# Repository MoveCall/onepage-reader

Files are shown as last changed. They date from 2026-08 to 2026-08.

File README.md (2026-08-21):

<div align="center">

<a href="https://github.com/MoveCall/onepage-reader">
  <picture>
    <source media="(prefers-color-scheme: dark)" srcset="assets/logo-dark.svg">
    OnePage Logo
  </picture>
</a>

# OnePage Reader

**Open-Hardware DIY E-Reader Ecosystem**  
*Firmware · Custom Board · Enclosure · Browser Tools*

<br/>







<br/>

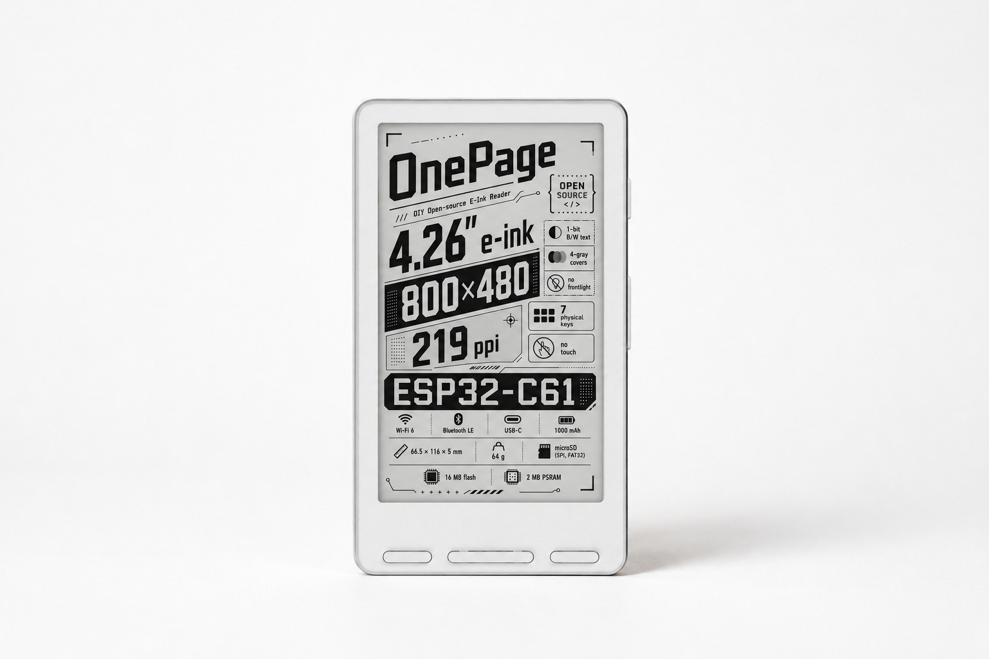
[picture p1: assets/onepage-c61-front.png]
OnePage C61 Front View


<br/>
<br/>

</div>

---

##  Overview

**OnePage** is an open-hardware DIY e-reader built around the **ESP32-C61** RISC-V wireless SoC. 

This repository serves as the central hub of the entire ecosystem: it houses the complete electronic fabrication packages (schematic, PCB, BOM, iBOM) and mechanical panel files, while aggregating the firmware, board SDK, and web companion tools via Git submodules.

---

##  Key Features

- **Next-Gen ESP32-C61**: Low-power RISC-V core with integrated Wi-Fi 6 and BLE.
- **BLE Page-Turner Remote**: Supports Bluetooth remote page turning with battery monitoring, key swapping, and live scanning.
- **Web Companion Tools**:
  - **Web Serial Flasher**: Flash firmware directly from Chromium-based browsers without local toolchain setups.
  - **Online Font Tool (`cpfont`)**: In-browser CJK font subsetting and glyph rasterization.
- **Production-Ready Hardware**: Complete gerbers, pick-and-place files, schematic PDF, and interactive BOM (iBOM).
- **Hybrid Craftsmanship**: Clean PET front and acrylic rear panels with an optional CNC mid-frame and MakerWorld 3D printable shell.

---

##  Ecosystem & Repositories

| Component | Submodule / Link | Description |
|:---|:---|:---|
|  **Firmware** | [`firmware/`](firmware) → [crosspoint-onepage](https://github.com/MoveCall/crosspoint-onepage) | Port of [CrossPoint Reader](https://github.com/crosspoint-reader/crosspoint-reader) tailored for OnePage C61 (`v0.1.0`). |
|  **Board SDK** | *(Nested in firmware)* → [onepage-reader-sdk-arduino](https://github.com/MoveCall/onepage-reader-sdk-arduino) | Arduino & PlatformIO board-support drivers (EPD, keys, power management, SD). |
|  **Electronics** | [`electronics/c61/`](electronics/c61/) | Schematic, Gerbers, BOM, iBOM, and SMT pick-and-place data. |
|  **Enclosure & Panels** | [`mechanical/c61/`](mechanical/c61/) → [MakerWorld](https://makerworld.com.cn/zh/@MoveCall) | Custom PET / Acrylic panels (`.epanm`), CNC mid-frame, and MakerWorld 3D models. |
|  **Web Tools** | [`web/`](web) → [onepage-reader-web](https://github.com/MoveCall/onepage-reader-web) | Official website, WebSerial flasher, and `cpfont` builder. |

---

##  Quick Start

### 1. Clone with all Submodules

To clone the entire project including firmware, drivers, and web tools in one shot:

```bash
git clone --recursive git@github.com:MoveCall/onepage-reader.git
```

If you already cloned without `--recursive`:
```bash
git submodule update --init --recursive
```

### 2. Flash Firmware via Browser

No need to install Python or compilation toolchains — visit the Web Flasher from Chrome / Edge to flash the latest release via USB-C:
[Open Web Flasher](https://github.com/MoveCall/onepage-reader-web)

---

##  Repository Layout

```text
onepage-reader/
├── firmware/        Submodule → crosspoint-onepage (nested: onepage-reader-sdk-arduino)
├── web/             Submodule → onepage-reader-web (browser flasher & font tools)
├── electronics/     PCB design, schematics & fabrication files per hardware variant
│   └── c61/
├── mechanical/      Panels (.epanm), CNC models (.stl) & MakerWorld 3D model links
│   └── c61/
└── assets/          Logos, graphics & media assets
```

---

##  Licensing

This is a **mixed-license** project designed to balance open hardware collaboration with design protection:

- **Electronics & Docs** (this repository): **[CC-BY-SA-4.0](https://creativecommons.org/licenses/by-sa/4.0/)** (`/electronics` may additionally carry **CERN-OHL-S** for hardware designs).
- **Firmware & SDK**: **[MIT](firmware/LICENSE)** (preserves CrossPoint Reader copyright).
- **3D Enclosure**: **[MakerWorld Exclusive License](https://makerworld.com.cn/zh/@MoveCall)** — 3D printable models are distributed exclusively via MakerWorld and are **not** stored directly in this repository.
- **OnePage Name & Logo**: All Rights Reserved.

---

##  Acknowledgements

- Built on top of the [CrossPoint Reader](https://github.com/crosspoint-reader/crosspoint-reader) project (MIT © Dave Allie). *(Not affiliated with CrossPoint or Xteink)*.
- Powered by Espressif ESP32-C61 & Open-Source Community.

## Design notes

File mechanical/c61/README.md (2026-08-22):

# OnePage enclosure & panels — ESP32-C61 (variant: c61)

## 3D Printable Enclosure (MakerWorld)

> **The full 3D printable enclosure models are published on MakerWorld under the MakerWorld Exclusive License.**  
> - Designer profile: **https://makerworld.com.cn/zh/@MoveCall**  
> - OnePage C61 enclosure model: **<model link — TBD after upload>**  

## Files in this Directory

### Front/Back Panels
- [`OnePage_Front_PET_Panel_v1.0.epanm`](OnePage_Front_PET_Panel_v1.0.epanm) — Front PET panel project (LCEDA / 立创面板定制工程)
- [`OnePage_Back_Acrylic_Panel_v1.0.epanm`](OnePage_Back_Acrylic_Panel_v1.0.epanm) — Back Acrylic panel project (LCEDA / 立创面板定制工程)
- [`OnePage_Panel_v1.0.dxf`](OnePage_Panel_v1.0.dxf) — 2D CAD panel fabrication drawing (laser cutting / CNC machining / CAD tools)

### Structural Parts
- [`OnePage_MidFrame_CNC_v1.0.step`](OnePage_MidFrame_CNC_v1.0.step) — CNC mid-frame 3D CAD model (STEP format for machining / CAM)
- [`OnePage_MidFrame_CNC_v1.0.stl`](OnePage_MidFrame_CNC_v1.0.stl) — CNC mid-frame 3D mesh model (STL format)

### Documentation & Guides (Planned)
- `assembly.md` *(optional)* — Assembly guide, screws & heat-set insert specs.
- `print-settings.md` *(optional)* — Recommended print settings and material guidelines.

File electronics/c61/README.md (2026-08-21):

# OnePage electronics — ESP32-C61 (variant: c61)

PCB design for the OnePage C61 board. Designed in **LCEDA / EasyEDA (立创EDA)**.

## Source of truth

- LCEDA source project — either the exported project file (`*.epro` / JSON) committed under
  `lceda/`, **or** the LCEDA open-hardware page on oshwhub: **<oshwhub link — TBD>**.
  (If the design lives on oshwhub, link it here and keep the exported/fab files below in-repo.)

## Hardware Release Files (V1 - 2026-08-19)

Tool-agnostic fabrication and review files for direct manufacturing or reference:

- **Schematic**: [`SCH_Sch_OnePage_V1_2026-08-19.pdf`](SCH_Sch_OnePage_V1_2026-08-19.pdf) — Complete circuit schematic.
- **Gerber / Fabrication**: [`Gerber_PCB_OnePage_V1_2026-08-19.zip`](Gerber_PCB_OnePage_V1_2026-08-19.zip) — PCB gerber & drill files for PCB manufacturing (JLCPCB / any PCB fab).
- **Bill of Materials (BOM)**: [`BOM_Board1_PCB_OnePage_V1_2026-08-19.csv`](BOM_Board1_PCB_OnePage_V1_2026-08-19.csv) — SMT component list.
- **Interactive BOM (iBOM)**: [`InteractiveBOM_PCB_OnePage_V1_2026-8-19.html`](InteractiveBOM_PCB_OnePage_V1_2026-8-19.html) — Visual component placement helper for manual assembly / inspection.
- **Pick and Place (CPL)**: [`PickAndPlace_PCB_OnePage_V1_2026_08_19.csv`](PickAndPlace_PCB_OnePage_V1_2026_08_19.csv) — SMT placement coordinates.
- **PCBA Preview**: [`pcb'a-pic.webp`](pcb'a-pic.webp) — Board rendering / photo.

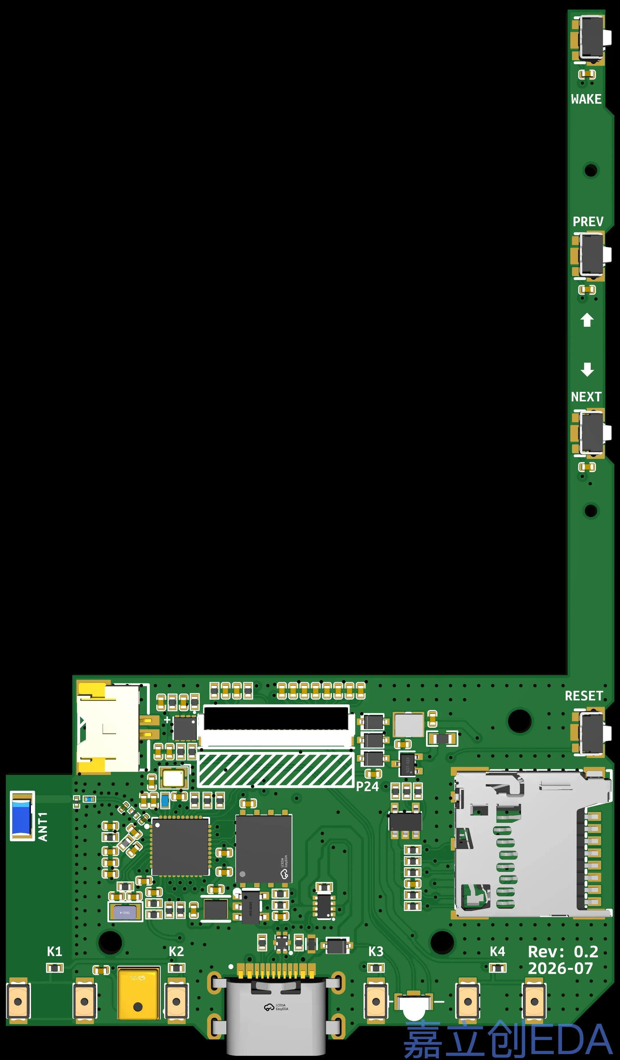
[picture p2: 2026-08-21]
electronics/c61/pcb'a-pic.webp

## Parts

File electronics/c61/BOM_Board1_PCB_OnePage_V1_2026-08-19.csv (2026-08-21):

Comment | Designator | Footprint | Quantity | Supplier Part
RFANT3216120A5T | ANT1 | FILTER-SMD_1206-2P-L3.2-W1.6-L | 1 | C127629
100nF | C1,C2,C11,C14,C16,C19,C21,C22,C26,C28,C34,C35,C36,C37 | C0402 | 14 | C41851,C307331
1uF | C3,C4,C6,C7,C8,C9,C10,C12,C13,C15,C17,C18,C23,C29,C38 | C0402 | 15 | C52923
4.7uF | C5 | C0402 | 1 | C2858031
10uF | C20,C24,C25,C27,C32,C39,C44 | C0402 | 7 | C15525
7pF | C30,C31 | C0402 | 2 | C368596
10nF | C33 | C0402 | 1 | C15195
12pF | C40,C41 | C0402 | 2 | C1547
0.8pF | C42 | C0201 | 1 | C408126
NC | C43 | C0201 | 1
5033981892 | CARD1 | TF-SMD_503398-1892 | 1 | C428492
BDFN2C051V | D1 | X1SON-2_L1.0-W0.6-P0.65-BI | 1 | C152024
B5817WS | D2,D3,D4,D5 | SOD-323_L1.7-W1.3-LS2.5-FD | 4 | C7420329
HC-FPC-05-09-24RLTAG | FPC1 | FPC-SMD_24P-P0.50_HC-FPC-05-09-24RLTAG | 1 | C5213757
A1254WR-S-2P | J1 | CONN-SMD_A1254WR-S-2P | 1 | C272975
TS3819ZJ 160gf | K1,K2,K3,K4 | KEY-SMD_TS3819ZJ | 4 | C6386917
10uH | L1 | IND-SMD_L2.5-W2.0 | 1 | C5832376
2nH | L2 | L0402 | 1 | C43365
2.2uH | L3 | IND-SMD_L2.0-W1.6-B | 1 | C5832344
27nH | L4 | IND-SMD_L1.0-W0.5-2 | 1 | C98057
4.3nH | L5 | L0201 | 1 | C2988753
ICMEF112P900MFR | L9 | FILTER-SMD_ICMEF112P900M-1 | 1 | C125058
NCD3010RG1 | LED1 | LED-SMD_NCD3010RG1 | 1 | C2917189
5.1kΩ | R1,R2 | R0402 | 2 | C25905
2.2Ω | R3 | R0603 | 1 | C2086340
1Ω | R4,R36 | R0402 | 2 | C25086
39kΩ | R5 | R0402 | 1 | C25783
10kΩ | R6,R8,R13,R15,R17,R19,R21,R22,R23,R24,R25,R26,R27,R29,R31,R35 | R0402 | 16 | C25744
5.1MΩ | R7,R12,R30 | R0402 | 3 | C270595
2.2kΩ | R9,R10 | R0402 | 2 | C25879
15kΩ | R11 | R0402 | 1 | C606169
NC | R14 | R0402 | 1
1.5kΩ | R16 | R0402 | 1 | C25867
100kΩ | R18 | R0402 | 1 | C25741
6.8kΩ | R20 | R0402 | 1 | C25917
45.3kΩ | R28 | R0402 | 1 | C137977
NC | R33 | R0201 | 1
0Ω | R34 | R0201 | 1 | C106227
VBACKUP | TP1,TP3 | TESTPOINT_2MM | 2
ESP32-C61HR2 | U1 | QFN-40_L5.0-W5.0-P0.40-TL-EP3.3 | 1
SI1308EDL | U2 | SOT-323-3_L2.0-W1.3-P1.30-LS2.1-BR | 1 | C7603347
LGS4056HDA | U3 | DFN-8_L2.0-W2.0-P0.50-TL-EP1.6 | 1 | C5124109
LMD4737T261-OAC02 | U4 | MIC-SMD_6P-L4.7-W3.8-P1.65-TL | 1 | C19267425
PY25Q128HA-WXH-IR | U5 | WSON-8_L6.0-W5.0-P1.27-TL-EP | 1 | C18208279
TS2306A 200gf 002 | U6,U7,U9,U10,U13,U14 | SW-SMD_L3.0-W2.0-LS3.5 | 6 | C5363482
MT9700-N | U8 | SOT-23-5_L2.9-W1.6-P0.95-LS2.9-BL | 1 | C42441843
EA8103AT5R | U11 | SOT-23-5_L2.9-W1.6-P0.95-LS2.8-BL | 1 | C53312128
LM66200DRLR | U12 | SOT-583-8_L2.1-W1.2-P0.50-LS1.6-BL | 1 | C3235556
TYPE-C 16P CB0.8 073 | USB1 | USB-C-SMD_TYPE-C-16P-CB0.8-073 | 1 | C2906289
40MHz | X1 | CRYSTAL-SMD_4P-L2.0-W1.6-BL-2 | 1 | C20885029
32.768kHz | X2 | FC-12M_L2.0-W1.2 | 1 | C99009

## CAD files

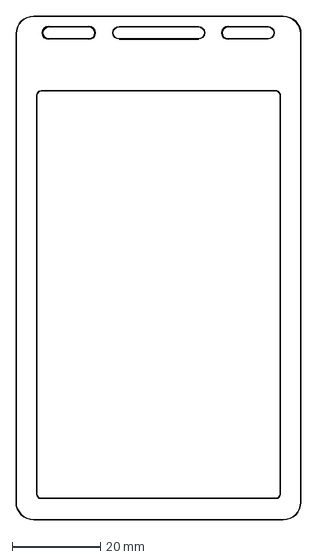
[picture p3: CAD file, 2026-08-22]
mechanical/c61/OnePage_Panel_v1.0.dxf
64.4 x 113.9 mm

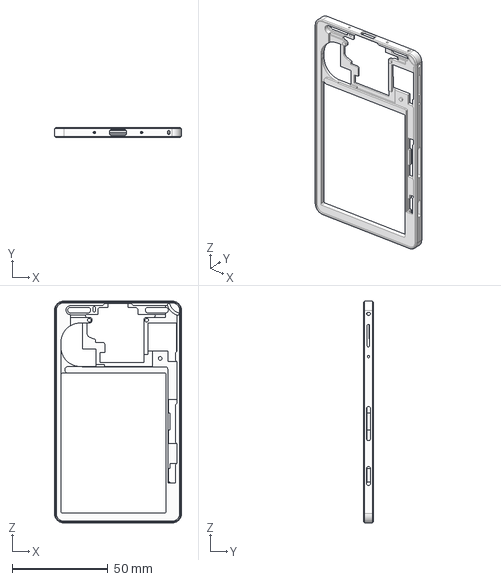
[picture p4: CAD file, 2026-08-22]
mechanical/c61/OnePage_MidFrame_CNC_v1.0.step
66.5 x 5.00 x 116.0 mm

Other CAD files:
mechanical/c61/OnePage_MidFrame_CNC_v1.0.stl

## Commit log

2026-07-27 Initial import: OnePage Reader project hub
    Super-project aggregating the OnePage open-hardware e-reader:
    - firmware/ submodule -> crosspoint-onepage (nested: onepage-reader-sdk-arduino)
    - web/ submodule -> onepage-reader-web
    - electronics/ skeleton for PCB (per variant); CC-BY-SA / optional CERN-OHL-S
    - mechanical/ points to MakerWorld (3D models under MakerWorld Exclusive License,
    NOT committed); .gitignore blocks *.stl/*.step to prevent leaking them
    - docs/ whole-device documentation
    Mixed-license: open electronics + firmware (MIT/CC-BY-SA/CERN-OHL-S), protected enclosure.
2026-08-21 feat: release v1 hardware & panels, update submodules, and modernize documentation
    [BOM_Board1_PCB_OnePage_V1_2026-08-19.csv, OnePage_MidFrame_CNC_v1.0.stl, PickAndPlace_PCB_OnePage_V1_2026_08_19.csv]
2026-08-22 feat(mechanical): add panel DXF drawing and CNC midframe STEP model
    [OnePage_MidFrame_CNC_v1.0.step, OnePage_Panel_v1.0.dxf]

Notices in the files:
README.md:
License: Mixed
